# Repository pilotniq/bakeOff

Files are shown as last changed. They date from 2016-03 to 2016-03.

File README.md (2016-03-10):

# bakeOff
"The missing power button for the Raspberry Pi"
Electronic circuit with On/Off button for Raspberry Pi

These are Eagle schematic and layout files for a circuit that plugs in between the RPi 
micro-USB power jack and the power supply. It has a button that when pressed sends a signal 
to the Raspberry pi to start shutting down safely. When it has shut down, power is cut.

Screw terminals allow you to use your own momentary or regular button. Another pair of screw
terminals let you supply other peripherals with power that is cut at the same time as the Raspberry Pi.
You need to run two wires from the board to the Pi - one for the shutdown signal, and one from Tx to 
sense when the Pi has shut down. There are also two jumpered pins where you can measure the current draw of the Pi.

See the project description on Hackaday: https://hackaday.io/project/9885-raspberry-pi-bake-off

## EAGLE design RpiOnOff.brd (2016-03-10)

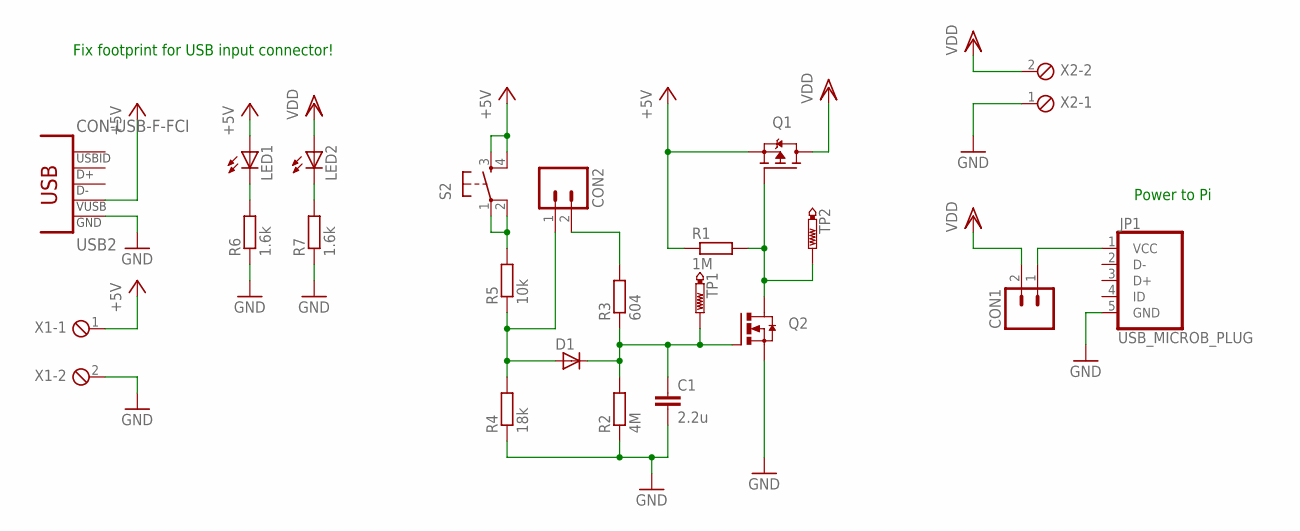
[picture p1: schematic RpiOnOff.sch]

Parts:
C1: 2.2u; C0603
CON1, CON2: CONNECTOR-1X2[2.54MM]; CONNECTOR-1X2-2.54MM
D1: D-A1-C3; SOT23
JP1: USB_MICROB_PLUG; CON-USB-MICRO-B-RA-SMT
LED1, LED2: LEDCHIP-LED0603; CHIP-LED0603
Q1: MOSFET-P-TOSHIBA-SSM3J338R; SOT23
Q2: MOSFET-N-SSM3K36MFV; SOT23
R1: 1M; R0603
R2: 4M; R0603
R3: 604; R0603
R4: 18k; R0603
R5: 10k; R0603
R6, R7: 1.6k; R0603
S2: TACT-4PINCK-PTS810; CK-PTS810
TP1, TP2: PTR1B1,27; B1,27
USB2: CON-USB-F-FCI; AMP-USB-MICROB
X1, X2: MPT2; 2POL254

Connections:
+5V: LED1.A, Q1.2 (S), R1.1, S2.3 (S), S2.4 (S1), USB2.1 (VUSB), X1.1
GND: C1.2, JP1.5 (GND), Q2.2 (S), R2.1, R4.1, R6.1, R7.1, USB2.5 (GND), X1.2, X2.1
unnamed: LED1.C, R6.2
unnamed: LED2.C, R7.2
unnamed: CON1.1, JP1.1 (VCC)
unnamed: R5.2, S2.1, S2.2 (P1)
Q1GATE: Q1.1 (G), Q2.3 (D), R1.2, TP2.TP
Q2GATE: C1.1, D1.3 (C), Q2.1 (G), R2.2, R3.1, TP1.TP
SENSE: CON2.1, D1.1 (A), R4.2, R5.1
TX: CON2.2, R3.2
VDD: CON1.2, LED2.A, Q1.3 (D), X2.2

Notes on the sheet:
Power to Pi
Fix footprint for USB input connector!

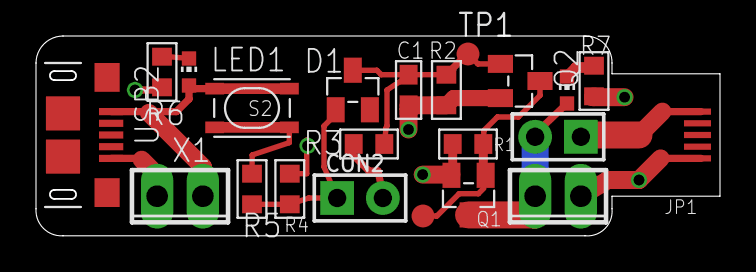
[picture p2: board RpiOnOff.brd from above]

Board: 2 copper layers, 38.0 x 11.1 mm, 22 parts (0 on the bottom side), 11 nets.

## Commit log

2016-02-26 Initial checkin, ready for PCB order.
    [RpiOnOff.brd, RpiOnOff.sch]
2016-03-10 I think the main change was fixing a transistor footprint.
    This is the version that was sent for production to Seeed Studios.
    [RpiOnOff.brd, RpiOnOff.sch]
